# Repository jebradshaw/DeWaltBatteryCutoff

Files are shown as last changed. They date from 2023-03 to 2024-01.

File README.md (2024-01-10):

# DeWaltBatteryCutoff
Please Note: This circuit is purely experimental. There has not been much testing on it - at all.

PCB using the RP2040 Pico microcontroller to monitor a 20V DeWalt battery and give an alarm and eventually shutoff the battery load to avoid deep discharging.

KiCAD PCB Design
I used the pico microcontroller KiCAD model from https://github.com/ncarandini/KiCad-RP-Pico, which is really nicely done!

rendered_3D_Image_KiCad2

The circuit uses a RP2040 Pico microcontroller to monitor the battery voltage from a buffered voltage divider on an ADC pin.  The user must turn on the board with an external temporary pushbutton and power MOSFET turns on supplying voltage to the regulator that turns on the pico microcontroller.  The Pico then latches the MOSFET on and begins to run the voltage monitoring program. When the battery reaches a set value (can be stored in EEPROM) a buzzer alarm begins to sound, getting more rapid as the battery voltage approaches the low voltage cutoff value.  Once that value is surpassed (with hysteresis) a 10 second timer begins and the output voltage is cutoff using a P-Channel MOSFET (currently using a 27 amp version FRP27P06) where the pico turns itself off.  Data is transmitted over the USB port at 115200 baud and eeprom values can be set and saved.  Output format is a serial ASCII string with the following format:

NAME, TIME, rate of discharge, battery voltage, Buzzer critical state, high voltage alarm, low voltage alarm

"PICOBATMON,T:3412691,dVdT:0.000,Bv:20.24,Bcrit:0,Halarm:17.50,Lalarm:17.00\r\n"

The control program was written using the Arduino IDE with the Raspberry Pi Pico/RP2040 board library.  The user can set and save specific parameters in the EEPROM such as voltage, gain (resistor divider ratio), and a brief description (string).

KiCAD PCB schematic design picture

Schematic of microcontroller circuit above.  PDF of Schematic can be downloaded here-> [PicoDeWalt_BattMonV2 Schematic.pdf](https://github.com/jebradshaw/DeWaltBatteryCutoff/files/11053368/PicoDeWalt_BattMonV2.Schematic.pdf)
 .

PCB_KiCad_snapshot

DeWaltBattMon_v10_FinalAssembledPCB

These printed circuit boards were made using Digikeys DK Red service and I am very happy with the results.

 To do list:  
   1. Turn on and off debugging through serial output terminal
   2. Implement Checksum?

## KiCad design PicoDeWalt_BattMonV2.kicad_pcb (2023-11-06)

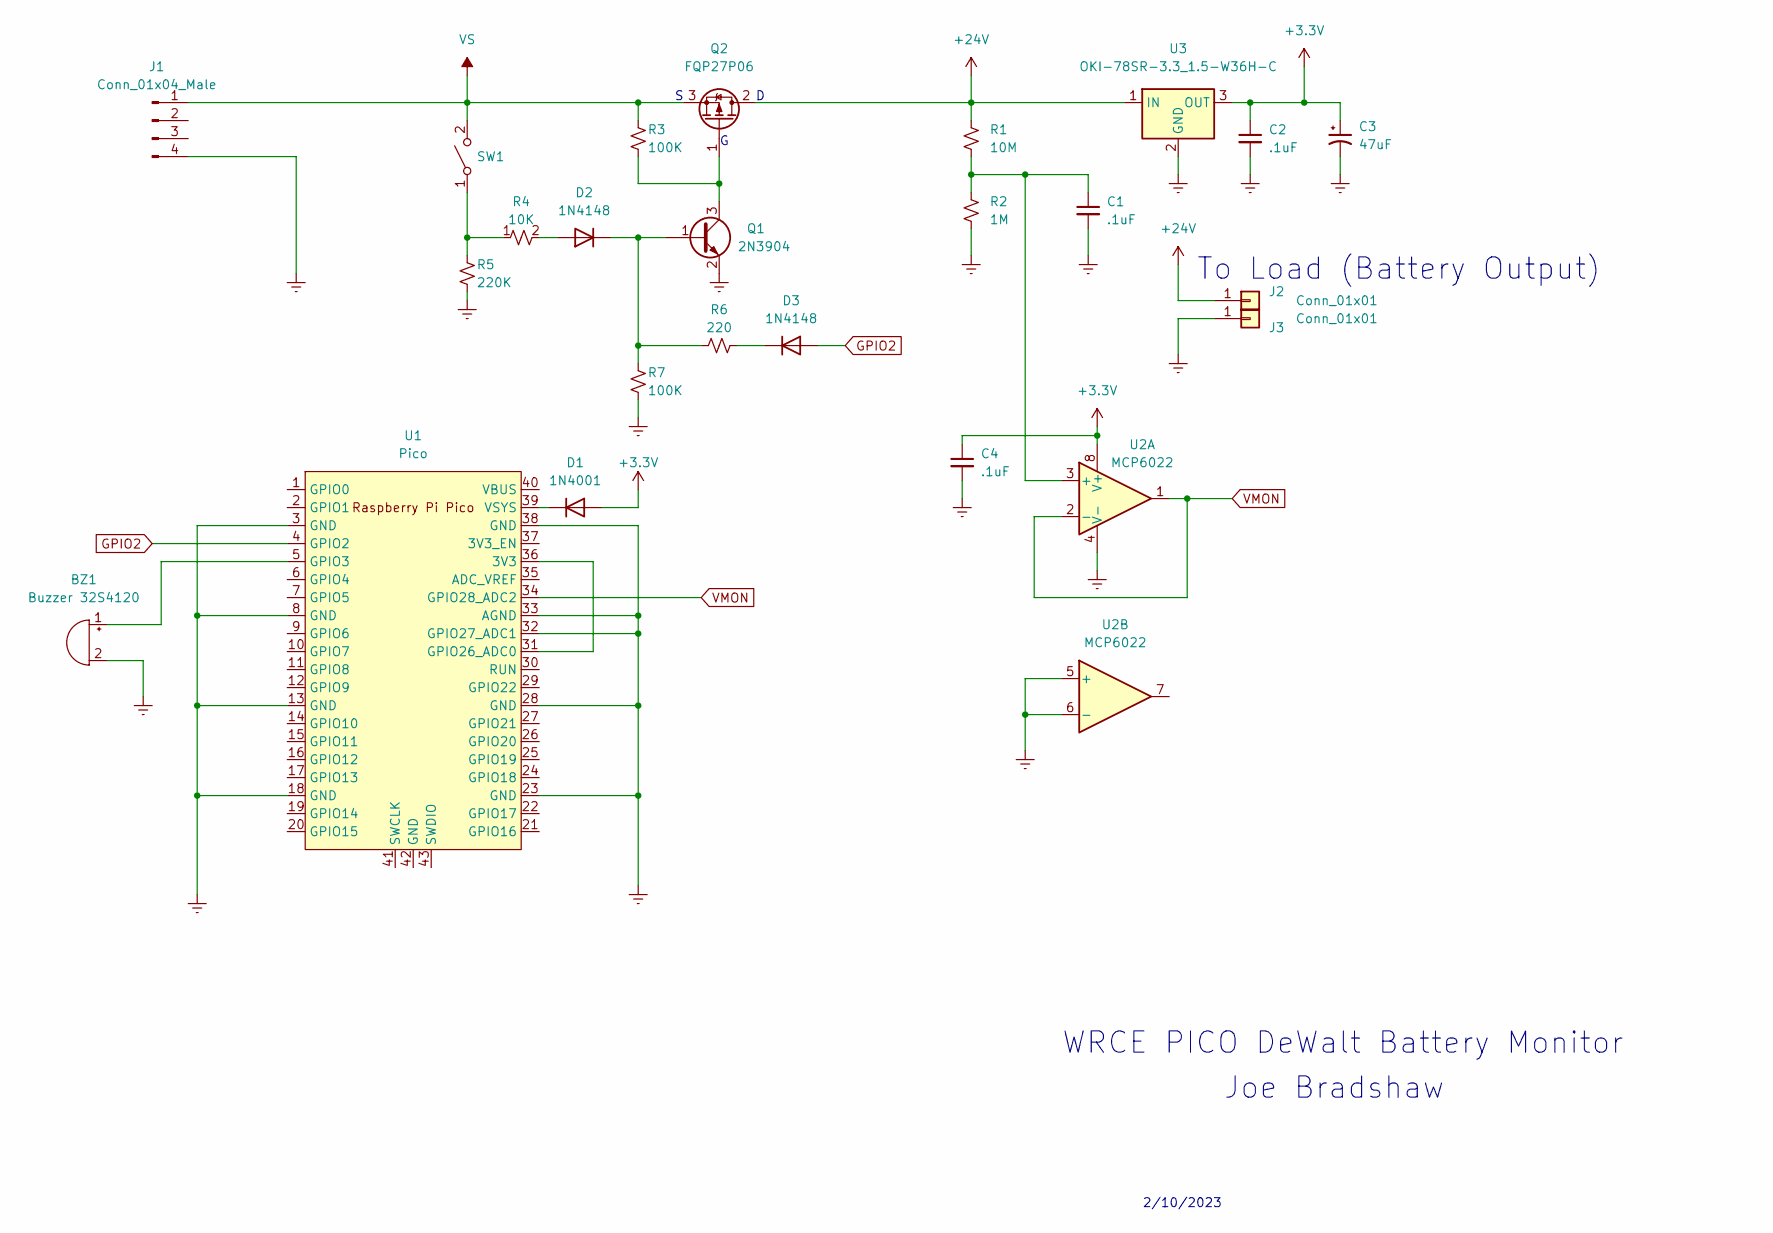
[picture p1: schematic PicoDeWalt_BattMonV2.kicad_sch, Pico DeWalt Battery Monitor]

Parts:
BZ1: Buzzer 32S4120; Buzzer_12x9.5RM7.6
C1, C4: .1uF; C_0805_2012Metric
C2: .1uF; C_0805_2012Metric_Pad1.18x1.45mm_HandSolder
C3: 47uF; CP_Elec_6.3x5.4_Nichicon
D1: 1N4001; D_DO-41_SOD81_P10.16mm_Horizontal
D2, D3: 1N4148; D_DO-35_SOD27_P7.62mm_Horizontal
J1: Conn_01x04_Male; DeWalt_battery_20V_Footprint
J2, J3: Conn_01x01; PowerPole_PCBmount_RA
Q1: 2N3904; SOT-23
Q2: FQP27P06; TO-220-3_Horizontal_TabDown
R1: 10M; R_0805_2012Metric
R2: 1M; R_0805_2012Metric
R3, R7: 100K; R_0805_2012Metric
R4: 10K; R_0805_2012Metric
R5: 220K; R_0805_2012Metric
R6: 220; R_0805_2012Metric
SW1: SW_SPST; JST_XH_B2B-XH-A_1x02_P2.50mm_Vertical
U1: Pico; RPi_Pico_SMD_TH
U2: MCP6022; SOIC-8_3.9x4.9mm_P1.27mm
U3: OKI-78SR-3.3_1.5-W36H-C; Converter_DCDC_Murata_OKI-78SR_Horizontal

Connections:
+3.3V: C2.1, C3.1, C4.1, D1.2 (A), U2.8 (V+), U3.3 (OUT)
+24V: J2.1, Q2.2 (D), R1.1, U3.1 (IN)
Earth: BZ1.2 (+), C1.2, C2.2, C3.2, C4.2, J1.4, J3.1, Q1.2 (E), R2.2, R5.2, R7.2, U1.3 (GND), U1.8 (GND), U1.13 (GND), U1.18 (GND), U1.23 (GND), U1.28 (GND), U1.32 (GPIO27_ADC1), U1.33 (AGND), U1.38 (GND), U2.4 (V-), U2.5 (+), U2.6 (-), U3.2 (GND)
GPIO2: D3.2 (A), U1.4 (GPIO2)
unnamed: BZ1.1 (-), U1.5 (GPIO3)
unnamed: C1.1, R1.2, R2.1, U2.3 (+)
unnamed: D1.1 (K), U1.39 (VSYS)
unnamed: D2.1 (K), Q1.1 (B), R6.1, R7.1
unnamed: D2.2 (A), R4.2
unnamed: D3.1 (K), R6.2
unnamed: Q1.3 (C), Q2.1 (G), R3.2
unnamed: R4.1, R5.1, SW1.1 (A)
unnamed: U1.31 (GPIO26_ADC0), U1.36 (3V3)
VMON: U1.34 (GPIO28_ADC2), U2.1, U2.2 (-)
VS: J1.1, Q2.3 (S), R3.1, SW1.2 (B)

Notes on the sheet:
2/10/2023
Joe Bradshaw
WRCE PICO DeWalt Battery Monitor
To Load (Battery Output)

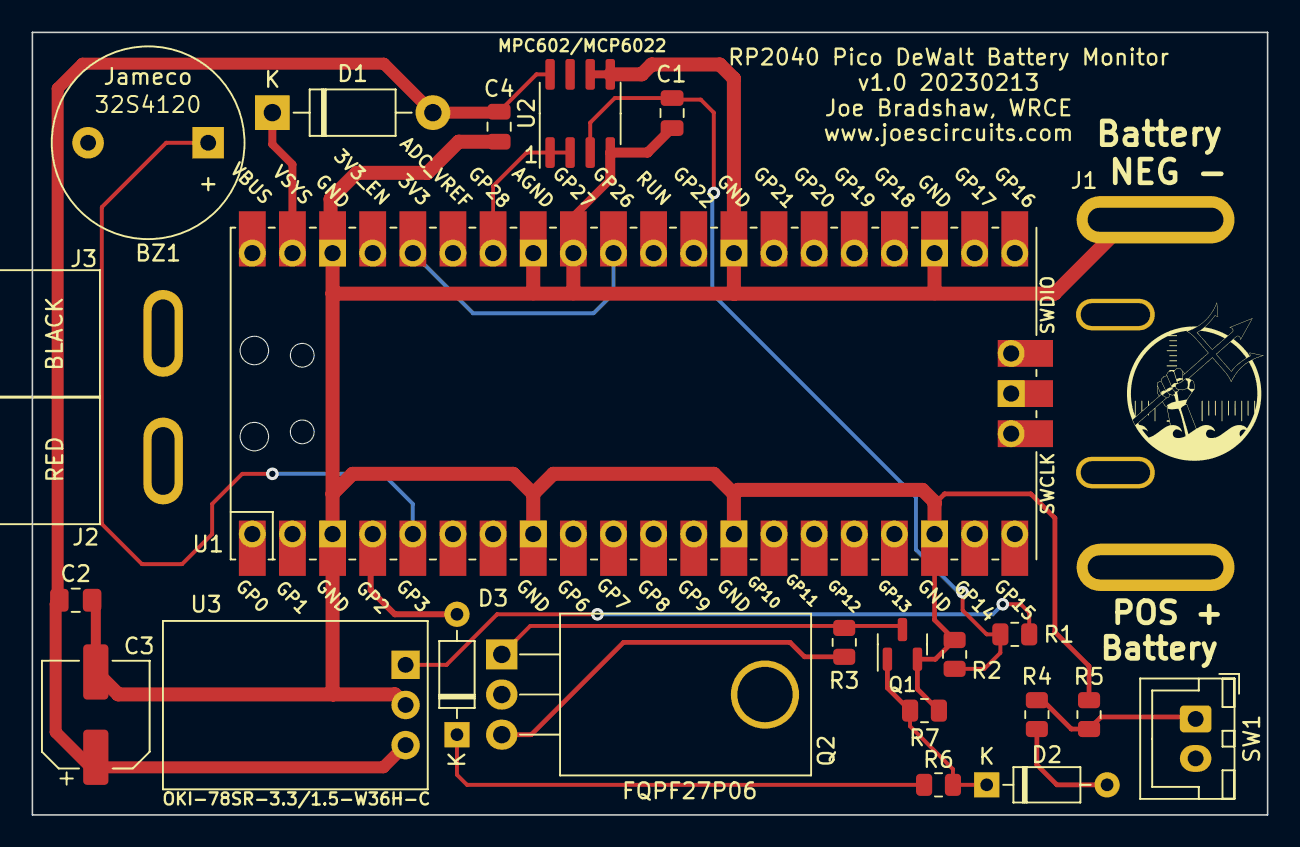
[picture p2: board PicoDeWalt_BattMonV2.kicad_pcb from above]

Board: 2 copper layers, 78.2 x 49.5 mm, 24 parts (0 on the bottom side), 15 nets.

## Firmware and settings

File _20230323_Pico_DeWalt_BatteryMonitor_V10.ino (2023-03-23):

// RasPi pico SURFER Vessel Interface board
//https://github.com/earlephilhower/arduino-pico/tree/master/cores/rp2040
#include <EEPROM.h>
#include "pico/stdlib.h"
#include <PicoAnalogCorrection.h> // https://github.com/Phoenix1747/Arduino-Pico-Analog-Correction
#include <math.h>

const uint8_t VCC_PIN = A0; // VCC meas pin
const uint8_t GND_PIN = A1; // GND meas pin
const uint8_t VIN_PIN = A2; // Vin pin to read the high voltage

const uint8_t ADC_RES = 12; // ADC bits

const uint8_t BUZZER_PIN = D3; // PWM Buzzer Ouput pin
PicoAnalogCorrection pico(ADC_RES, 1, 4078);

#define CRIT_TIMOUT_SEC     10    //  Set timeout seconds before shutdown when critical voltage low level is reached

float gainCalc = 10.660;    //voltage scale time resistor voltage divider gain (10M/1M ohm)
float highAlarmVolts = 17.5;
float lowAlarmVolts = 17.0;
float criticalLowVolts = 16.6;
int criticalCounter = 0;
int critCntLastTime = 0;

static unsigned long millisLastLed = 0;
static unsigned long millisLedDelay = 100;
static unsigned long millisLastBuzzer = 0;
static unsigned long millisLastSerial = 0;
static unsigned long millisSerialDelay = 1000;

int led = LED_BUILTIN; // the PWM pin the LED is attached to
static int batteryState = 1;
static int buzzerState = 0;
static int buzzerTime = 100;
static int buzzerCrit = 0;

// start assuming battery is charged and going down
float battVolts, battVoltsLast;
float NoAlarmHysVolts = -0.1;
float NormAlarmHysVolts = -0.1;
int dir = 0; // negative is moving down, positive if moving up

float dVdT;
float dVdT_avg;

int eeAddress = 0;   //Location we want the data to be put.
struct MemObject {  
  char descriptionStr[20];
  float gainCalc;  
  float highAlarmVolts;
  float lowAlarmVolts;
};

void buzzerUp(void){
  analogWriteFreq(1000);     // set freq output to 2KHz   
  analogWrite(BUZZER_PIN, 512);     // turn on PWM 
  digitalWrite(led, !digitalRead(led));
  delay(200); 
  analogWrite(BUZZER_PIN, 0);     // turn off PWM 
  digitalWrite(led, !digitalRead(led));
  delay(100);

  analogWriteFreq(800);     // set freq output to 2KHz   
  analogWrite(BUZZER_PIN, 512);     // turn on PWM 
  digitalWrite(led, !digitalRead(led));
  delay(200); 
  analogWrite(BUZZER_PIN, 0);     // turn off PWM 
  digitalWrite(led, !digitalRead(led));
  delay(100);

  analogWriteFreq(600);     // set freq output to 2KHz   
  analogWrite(BUZZER_PIN, 512);     // turn on PWM 
  digitalWrite(led, !digitalRead(led));
  delay(200); 
  analogWrite(BUZZER_PIN, 0);     // turn off PWM 
  digitalWrite(led, !digitalRead(led));
  delay(100);    
}

void buzzerDown(void){
  analogWriteFreq(600);     // set freq output to 2KHz   
  analogWrite(BUZZER_PIN, 512);     // turn on PWM 
  digitalWrite(led, !digitalRead(led));
  delay(200); 
  analogWrite(BUZZER_PIN, 0);     // turn off PWM 
  digitalWrite(led, !digitalRead(led));
  delay(100);

  analogWriteFreq(800);     // set freq output to 2KHz   
  analogWrite(BUZZER_PIN, 512);     // turn on PWM 
  digitalWrite(led, !digitalRead(led));
  delay(200); 
  analogWrite(BUZZER_PIN, 0);     // turn off PWM 
  digitalWrite(led, !digitalRead(led));
  delay(100);

  analogWriteFreq(1000);     // set freq output to 2KHz   
  analogWrite(BUZZER_PIN, 512);     // turn on PWM 
  digitalWrite(led, !digitalRead(led));
  delay(200); 
  analogWrite(BUZZER_PIN, 0);     // turn off PWM 
  digitalWrite(led, !digitalRead(led));
  delay(100);    
}

void setup() {
    // Make D2 the output to turn off the P-Channel MOSFET when triggered
  //digitalWrite(D2, HIGH);
  pinMode(D2, OUTPUT);
  digitalWrite(D2, HIGH);    
  pinMode(led, OUTPUT);

   buzzerUp();
   
//  analogWriteFreq(2000);     // set freq output to 2KHz
//  for(int i = 0;i<3;i++){    
//    analogWrite(BUZZER_PIN, 512);     // turn on PWM 
//    digitalWrite(led, !digitalRead(led));
//    delay(200); 
//    analogWrite(BUZZER_PIN, 0);     // turn off PWM 
//    digitalWrite(led, !digitalRead(led));
//    delay(100);
//    analogWriteFreq(2000 + (i*1000));     // set freq output to 2KHz
//  }  
       
  MemObject eepromData;  // create an object for the eeprom data
  //delay(2000);
  //set_sys_clock_khz(10000, true); // Set System clock to 10000 kHz


//  Uncomment out for the first time programming
//    eeAddress = 0;
//    eepromData.highAlarmVolts = highAlarmVolts;
//    eepromData.lowAlarmVolts = lowAlarmVolts;
//    eepromData.gainCalc = gainCalc;
//    EEPROM.put(eeAddress, eepromData);
//    delay(20);
//    EEPROM.commit();
    
  //Serial.setTimeout(20000); // allow up to 20 seconds to receive command
  Serial.begin(115200);
  Serial.printf("PICO BATTERY MONITOR V1.0 - 20230323 J.Bradshaw\r\n");
  EEPROM.begin(256);          // must be called before using the 4K chunk of flash at the end of flash space 

  //analogReadResolution(12);
   analogWriteFreq(1000);     // set freq output to 1KHz

  pinMode(GND_PIN, INPUT);
  pinMode(VCC_PIN, INPUT);

  analogReadResolution(ADC_RES);  

    // find initial condition state
   battVolts = (float)(pico.analogCRead(VIN_PIN, 10)/4095.0 * 3.3) * gainCalc;  // 10M / 1M voltage divider * adc pin voltage
   battVoltsLast = battVolts;
   if(battVolts >= highAlarmVolts){
      dir = 1;
   }
   else if((battVolts < highAlarmVolts) && (battVolts >= criticalLowVolts)){
      dir = 0;
   }
   else if(battVolts < criticalLowVolts){
      dir = -1;
   }

  eeAddress = 0;

  Serial.printf("Reading EEPROM:\r\n");
  // read the eeprom memory
  EEPROM.get(eeAddress, eepromData);  
  delay(20);
  Serial.printf("DescStr=%s\r\n", eepromData.descriptionStr);  
  Serial.printf("Resistor Gain Factor= %7.2f\r\n", eepromData.gainCalc);
  Serial.printf("Alarm On Voltage= %7.2f\r\n", eepromData.highAlarmVolts);
  Serial.printf("Low Voltage Cutoff = %7.2f\r\n", eepromData.lowAlarmVolts);
  //delay(3000);
  //Serial.println(eepromData.absoluteCutoffVolts);
  
  // Has the eeprom ever been set?
//   if(!isinf(eepromData.highAlarmVolts) || !isinf(eepromData.lowAlarmVolts) || !isinf(eepromData.gainCalc)){
//    Serial.printf("Setting eeprom to default values");
//    delay(1000);
//    strcpy(eepromData.descriptionStr, "DeWalt Batt Tester\0"); // copies the second string passed to the function to the first function
//    eepromData.highAlarmVolts = highAlarmVolts;
//    eepromData.lowAlarmVolts = lowAlarmVolts;
//    eepromData.gainCalc = gainCalc;
//    EEPROM.put(eeAddress, eepromData);
//    delay(20);
//    EEPROM.commit();
//    delay(2000);
//    EEPROM.get(eeAddress, eepromData);  
//    delay(20);
//    Serial.printf("DescStr=%s\r\n", eepromData.descriptionStr);  
//    Serial.printf("Resistor Gain Factor= %7.2f\r\n", eepromData.gainCalc);
//    Serial.printf("Alarm On Voltage= %7.2f\r\n", eepromData.highAlarmVolts);
//    Serial.printf("Low Voltage Cutoff = %7.2f\r\n", eepromData.lowAlarmVolts);
//    delay(2000);
//  }
//  else{ // else update with eeprom stored value
//    highAlarmVolts = eepromData.highAlarmVolts;
//    lowAlarmVolts = eepromData.lowAlarmVolts;
//    gainCalc = eepromData.gainCalc;
//  }
  
}

// core 1
void setup1() {

}

void loop1() {

}

void loop() {
  int lv_cutoff_cnt = 0;
  
  //int adc0 = analogRead(VIN_PIN);
    float battVolts = 0.0;
    //battVolts = ((float)analogRead(VIN_PIN)/4095.0 * 3.256) * 11.0;  // 10M / 1M voltage divider * adc pin voltage
    //for(int i=0;i<100;i++){
      battVolts = (float)(pico.analogCRead(VIN_PIN, 10)/4095.0 * 3.3) * gainCalc;  // 10M / 1M voltage divider * adc pin voltage
    //}
    //battVolts /= 100.0;    

    // sort the condition based on the battery voltage
    if(battVolts >= highAlarmVolts){     
      NoAlarmHysVolts = -0.1;  // Add small negative hysteresis volts for detection until crossed        

      dir = 1;
      analogWrite(BUZZER_PIN, 0);     // turn off PWM 
      digitalWrite(D2, HIGH); // turn on the P-Channel Power FET (Source input voltage to the load)
      buzzerState = 0;
       buzzerCrit = 0;
       millisLedDelay = 300;
    }
    
    if((battVolts < (highAlarmVolts + NoAlarmHysVolts)) && (battVolts >= (lowAlarmVolts + NormAlarmHysVolts))){
      if(dir == 1){ // if the normal alarm volts is negative, going down
        NoAlarmHysVolts = .2; // add .1 volts to No Alarm detect hysteresis        
      }
      if(dir == -1){ //going up
        NormAlarmHysVolts = -.2; // add .1 volts to No Alarm detect hysteresis         
      }
      dir = 0;
//      NormAlarmHysVolts = .2;  // Add small negative hysteresis volts to Normal Alarm crossover detection
      analogWriteFreq(1000);     // set freq output to 1KHz
      buzzerCrit = 0;      
      millisLedDelay = 200;
      switch(buzzerState){
        case 1:
          analogWrite(BUZZER_PIN, 100);        
          millisLastBuzzer = millis();
          buzzerTime = 500;   //half second beep
          buzzerState = 2;
          break;
        case 2:
          if(millis() > millisLastBuzzer + buzzerTime){
              millisLastBuzzer = millis();
              analogWrite(BUZZER_PIN, 0);
              buzzerTime = (int)(((battVolts - lowAlarmVolts) / (highAlarmVolts - lowAlarmVolts)) * 5000); // wait percentage of 5 seconds
              buzzerState = 3;
          }
          break;
        case 3:
          if(millis() > millisLastBuzzer + buzzerTime){
              buzzerState = 1;
          }
          break;
       default:
        buzzerState = 1;
        break;
      }                      
    }
    
    if((battVolts < (lowAlarmVolts + NormAlarmHysVolts)) && (battVolts >= criticalLowVolts)){
      if(dir == 0){
        NormAlarmHysVolts = .2; // add .1 volts to No Alarm detect hysteresis 
      }
      dir = -1;
      //digitalWrite(D2, LOW); // turn off the P-Channel Power FET (Pinch off the voltage source to the load)
      analogWriteFreq(2000);     // set freq output to 2KHz      
      millisLedDelay = 100;
      buzzerCrit = 1;
      switch(buzzerState){
        case 4:
          analogWrite(BUZZER_PIN, 512);         // Duty Cycle for Loudness
          millisLastBuzzer = millis();
          buzzerTime = 500;   //half second beep
          buzzerState = 5;
          break;
        case 5:
          if(millis() > millisLastBuzzer + buzzerTime){
              millisLastBuzzer = millis();
              analogWrite(BUZZER_PIN, 0);
              buzzerTime = 1000; // wait 5 seconds
              buzzerState = 6;
          }
          break;
        case 6:
          if(millis() > millisLastBuzzer + buzzerTime){
              buzzerState = 4;
          }
          break;
       default:
        buzzerState = 4;
        break;
      }       
    }

  if(battVolts < criticalLowVolts){
    if(buzzerCrit != 2){
      Serial.printf("Critical Voltage level reached, starting counter!\r\n");
      buzzerCrit = 2;
      criticalCounter=0;
      critCntLastTime = millis();
    }
    else{      
      if(millis() - critCntLastTime > 1000){
        critCntLastTime = millis();
        criticalCounter++;
        analogWriteFreq(2000);
        analogWrite(BUZZER_PIN, 512);     // turn on PWM 
        digitalWrite(led, !digitalRead(led));
        delay(500); 
        analogWrite(BUZZER_PIN, 0);     // turn off PWM 
        digitalWrite(led, !digitalRead(led));        
        Serial.printf("\r\nCritical Timeout left in seconds = %d\r\n", CRIT_TIMOUT_SEC - criticalCounter);
        if(criticalCounter > CRIT_TIMOUT_SEC){ // seconds until timeout and shutoff
          //sleep
          //delay(2000);

          buzzerDown();
          
          Serial.printf("\r\nPROGRAM TRAP\r\n");
          digitalWrite(D2, LOW); // turn off the P-Channel Power FET (Pinch off the voltage source to the load)
          analogWrite(BUZZER_PIN, 0);     // turn off PWM
          digitalWrite(led, LOW); //  turn off LED

          // ----------------------------------------------------------------------------------------
          // under normal operation the program would trap here by turning itself off, but if USB connected it will stay on
          int exitTrap = 1;
          buzzerState = -1;
          while(exitTrap){            
            digitalWrite(led, HIGH); //  turn on LED
            delay(300);
            digitalWrite(led, LOW); //  turn off LED
            delay(700);   
            battVolts = (float)(pico.analogCRead(VIN_PIN, 10)/4095.0 * 3.3) * gainCalc;
            if(battVolts > criticalLowVolts){
              exitTrap = 0;              
            }
            //Serial.printf("\r\nProgram trap ");
            //Serial.printf("PICOBATMON,T:%d,dVdT:%.3f,Bv:%.2f,Bcrit:%d,Bstate:%d,buzzT:%d,Halarm:%.2f,Lalarm:%.2f\r\n", millis(), dVdT, battVolts, buzzerCrit, buzzerState, buzzerTime, highAlarmVolts, lowAlarmVolts);
            Serial.printf("PICOBATMON,T:%d,dVdT:%.3f,Bv:%.2f,Bcrit:%d,Halarm:%.2f,Lalarm:%.2f\r\n", millis(), dVdT, battVolts, buzzerCrit, highAlarmVolts, lowAlarmVolts);
          }
          digitalWrite(D2, HIGH); // turn on the P-Channel Power FET (Pinch off the voltage source to the load)
          buzzerUp();
          buzzerCrit=0;
          buzzerState=0;                  
          // !!! If it did not turn itself off then the USB port is supplying power to the microcontroller and 
          //  the program will simply start at the top of the loop again...          
        }
      }        
    }    
  }

  // LED flash rate
  if(millis() > millisLastLed + millisLedDelay){
    millisLastLed = millis();          
    
    digitalWrite(led, !digitalRead(led));
  } 

  // Update the serial output
  if(millis() > millisLastSerial + millisSerialDelay){
    dVdT = (battVolts - battVoltsLast) * ((millis()-millisLastSerial)/1000.0);
    
    millisLastSerial = millis();
    battVoltsLast = battVolts;    

    //Serial.printf("%d dVdT=%7.3f Battery Voltage = %7.2f buzzerCrit=%d state=%d buzzTime=%d HighAlarmV=%7.2f LowAlarmV=%7.2f\r\n", millis(), dVdT, battVolts, buzzerCrit, buzzerState, buzzerTime, highAlarmVolts, lowAlarmVolts);
    //Serial.printf("PICOBATMON,T:%d,dVdT:%.3f,Bv:%.2f,Bcrit:%d,Bstate:%d,buzzT:%d,Halarm:%.2f,Lalarm:%.2f\r\n", millis(), dVdT, battVolts, buzzerCrit, buzzerState, buzzerTime, highAlarmVolts, lowAlarmVolts);
    Serial.printf("PICOBATMON,T:%d,dVdT:%.3f,Bv:%.2f,Bcrit:%d,Halarm:%.2f,Lalarm:%.2f\r\n", millis(), dVdT, battVolts, buzzerCrit, highAlarmVolts, lowAlarmVolts);
  }
  
// check is a serial character was received
  if(Serial.available()>0){
    char str[30];

    if(Serial.peek() == '?'){ // ? display commands
        int dummy = Serial.read();  
        Serial.printf(" SINGLE CHARACTER COMMANDS  \r\n");
        Serial.printf("'?' - display this menu\r\n");
        delay(10);
        Serial.printf(" STRING COMMANDS (followed by carriage return '\\r') \r\n");
        Serial.printf("voltsIn F1\\r - When supplying a known voltage F1(float), auto calculates the gain from voltage divider\r\n");
        delay(10);
        Serial.printf("eepromr\\r - read the current values in the EEPROM\r\n");
        Serial.printf("eepromw S1 F1 F2\\r - write to EEPROM, S1 is string description, F1 high alarm volts, F2 low alarm volts\r\n");
        Serial.printf("setgain F1\\r - Set the Gain of the voltage divider (around 11.0)\r\n");
        Serial.printf("adccal\\r - Calibrate the ADC\r\n");       

        // clar out any additional characters in the Serial buffer
        while(Serial.available()){
          char c = Serial.read();
        }

        // wait for single character press to exit menu
        while(!Serial.available()); 
        char c = Serial.read();       // expunge new character entered in buffer
      }

    // extract string commands
    Serial.readBytesUntil('\r', str, 30);
    
    if(strncmp(str, "voltsIn ", 8) == 0){
      float voltsIn;
      int numvals = sscanf(str, "voltsIn %f\r", &voltsIn);
      if(numvals == 1){                
        if(voltsIn < 0.0)
          voltsIn = 0.0;
        if(voltsIn > 100.0)
          voltsIn = 100.0;
          
        Serial.printf("\r\nVoltsIn = %7.3f\r\n", voltsIn);     
        gainCalc = voltsIn / ((float)(pico.analogCRead(VIN_PIN, 10)/4095.0) * 3.3);        
        Serial.printf("\r\nGain Calc = %7.3f\r\n", gainCalc);     
        delay(2000);
        MemObject eepromData;
        eeAddress = 0;   //Location we want the data to get
        eepromData.gainCalc = gainCalc;
        EEPROM.put(eeAddress, eepromData);

        EEPROM.commit();  // Writes the updated data to flash, so next reboot it will be readable
      }
      else{
        Serial.printf("ERROR - num parameters scanned is %d", numvals);
        delay(2000);
      }
    }// if received command was voltsIn

    if(strncmp(str, "eepromr", 7) == 0){      
        MemObject eepromData;
        eeAddress = 0;   //Location we want the data to get
        EEPROM.get(eeAddress, eepromData);
        //Serial.printf(MOVE_L_C, 20, 0);
        Serial.println(eepromData.descriptionStr);
        Serial.println(eepromData.gainCalc);
        Serial.println(eepromData.highAlarmVolts);
        Serial.println(eepromData.lowAlarmVolts);
        //Serial.println(eepromData.absoluteCutoffVolts);

        delay(3000);
      }// eeprom command

      // write eeprom command
      if(strncmp(str, "eepromw ", 8) == 0){
        char tempStr[20] = {0,0,0,0,0,0,0,0,0,0,0,0,0,0,0,0,0,0,0,0};
        //float tempgainCalc = 11.0;
        float temphighAlarmVolts = 16.5;
        float templowAlarmVolts = 16.0;
        //float tempabsoluteCutoffVolts = 15.6;
        
        int numvals = sscanf(str, "eepromw %s %f %f", tempStr, &temphighAlarmVolts, &templowAlarmVolts);

        Serial.printf("\r\nSerial read - eepromw %s %f %f\r\n", tempStr, temphighAlarmVolts, templowAlarmVolts);        

        Serial.printf("Old eeprom vals are :\r\n");
        eeAddress = 0;

        MemObject eepromDatar;  // create an object for the eeprom data
        EEPROM.get(eeAddress, eepromDatar);
        Serial.println(eepromDatar.gainCalc);    //This may print 'ovf, nan' if the data inside the EEPROM is not a valid float.
        Serial.println(eepromDatar.descriptionStr);       
        Serial.println(eepromDatar.highAlarmVolts);
        Serial.println(eepromDatar.lowAlarmVolts);        
        
        if(numvals == 3){ // Successfully scanned 3 values
          MemObject eepromData;  // create an object for the eeprom data
          
          strcpy(eepromData.descriptionStr, tempStr); // copies the second string passed to the function to the first function
          eepromData.gainCalc = gainCalc;
          eepromData.highAlarmVolts = temphighAlarmVolts;
          eepromData.lowAlarmVolts = templowAlarmVolts;
        
          EEPROM.put(eeAddress, eepromData);
  
          eeAddress = 0;   //Location we want the data to get
          EEPROM.get(eeAddress, eepromData);
          Serial.printf("Number of parameters parsed was %d\r\n", numvals);
          Serial.println(eepromData.gainCalc);    //This may print 'ovf, nan' if the data inside the EEPROM is not a valid float.
          Serial.println(eepromData.descriptionStr);       
          Serial.println(eepromData.highAlarmVolts);
          Serial.println(eepromData.lowAlarmVolts);

          EEPROM.commit();  // Writes the updated data to flash, so next reboot it will be readable
          
          highAlarmVolts = eepromData.highAlarmVolts;
          lowAlarmVolts = eepromData.lowAlarmVolts;
        }
        else{          
          Serial.printf("Number of parameters parsed was %d", numvals);
          delay(2000);
        }
      } // eepromw command

      // set gain value (resistor voltage divider
      if(strncmp(str, "setgain ", 8) == 0){
        float tempSetGain = 0.0;
        int numvals = sscanf(str, "setgain %f", &tempSetGain);

        Serial.printf("\r\nSerial read - setgain %f\r\n", tempSetGain);

        Serial.printf("Old eeprom gain was :\r\n");
        eeAddress = 0;

        MemObject eepromDatar;  // create an object for the eeprom data
        EEPROM.get(eeAddress, eepromDatar);
        Serial.println(eepromDatar.gainCalc);    //This may print 'ovf, nan' if the data inside the EEPROM is not a valid float.

        MemObject eepromData;  // create an object for the eeprom data
          
        eepromData.gainCalc = tempSetGain;

        eeAddress = 0;
        EEPROM.put(eeAddress, eepromData);

        EEPROM.commit();  // Writes the updated data to flash, so next reboot it will be readable        
          
        eeAddress = 0;
        
        EEPROM.get(eeAddress, eepromDatar);
        Serial.println(eepromDatar.gainCalc);    //This may print 'ovf, nan' if the data inside the EEPROM is not a valid float.
        Serial.println(eepromDatar.descriptionStr);       
        Serial.println(eepromDatar.highAlarmVolts);
        Serial.println(eepromDatar.lowAlarmVolts); 

          gainCalc = tempSetGain;
      }
  // calibrate the on-board ADC
  if(strncmp(str, "adccal", 6) == 0){ 
      Serial.print("Offset Values: ");
      pico.returnCalibrationValues();
    
      Serial.print("Uncalibrated GND: ");
      Serial.println(pico.analogRead(GND_PIN));
      Serial.print("Calibrated GND: ");
      Serial.println(pico.analogCRead(GND_PIN,10));
    
      Serial.print("Uncalibrated VCC: ");
      Serial.println(pico.analogRead(VCC_PIN));
      Serial.print("Calibrated VCC: ");
      Serial.println(pico.analogCRead(VCC_PIN,10));
      Serial.println();
    
      delay(1000);
    // Calibrate ADC using an average of 5000 measurements
    pico.calibrateAdc(GND_PIN, VCC_PIN, 5000);
    
    PicoAnalogCorrection pico(ADC_RES, pico.analogCRead(GND_PIN,10), pico.analogCRead(VCC_PIN,10));    
  }        
    //clear out any garbage in buffer
   while(Serial.available()>0){
      char c = Serial.read();
   }   
  }//serial available

  delay(20);    
  
} // loop

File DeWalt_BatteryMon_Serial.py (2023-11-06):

import serial
import time as t

ser = serial.Serial('/dev/ttyACM0', 115200, timeout = .005)

print('Connected to:', ser.portstr)

while True:
    ser.flush()
    t.sleep(.1)
    line = ser.readline().rstrip().decode() # read the string
    str_line = line.split(',')
    if str_line != ['']:
        if str_line[0] == 'PICOBATMON':
            battVoltsStr = str_line[3].split(':')
            criticalState = str_line[4].split(':')
            
            print(str_line)
            
            battVolts = float(battVoltsStr[1])            
            critState = int(criticalState[1])
            
            print('Battery Voltage = ' + str(battVolts) + ' ' + 'CriticalState = ' + str(critState))
            
            if battVolts <= 17.0:
                print("Warning - Battery is getting low!")
            if critState == 2:
                print("Run shutdown script ASAP")
                t.sleep(2)
    
    xnums = len(str_line)
    
    

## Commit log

2023-11-06 Add files via upload
    KiCad PCB files uploaded
    [PicoDeWalt_BattMonV2.kicad_pcb, PicoDeWalt_BattMonV2.kicad_sch]
2023-11-06 Add files via upload
    External files for Anderson powerpole .STEP, DeWalt battery connector PCB footprint, WRCE logo, and RA powerpole PCB mount footprint.
2023-11-06 Add files via upload
    DeWalt_BatteryMon_Serial.py is a python example of reading the serial stream from the DeWalt battery monitor with a Raspberry Pi connected over USB as a serial device.
